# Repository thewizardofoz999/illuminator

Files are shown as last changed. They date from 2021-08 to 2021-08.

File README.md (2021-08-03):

# Illuminator

Completely open-source LED board for FRC visual processing tasks.

Idea based on: Sneaky Snakes' Gloworm LEDboard: https://github.com/KahramanAkyuz/Gloworm and
               Gloworm Vision's Gloworm: https://github.com/gloworm-vision/gloworm

Index:

• "Illuminator" is the first version of the design.

• "Illuminator BOOST" is an upgrade board for ILL.v1.

• "Illuminator" is the second version. This version has a MCU (ATmega328) and temperature sensors on both side of the board. Thus it can work with a closed feedback loop algorithm. We'we written an Arduino IDE library for the v2 board. Library files are also included in the repository in software folder.

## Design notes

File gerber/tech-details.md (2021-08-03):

# PCB Specifications:

Layers: 2 Layers

Min Track/Spacing: 6/6mil

Min Hole Size: 0.3mm

Via Process: Tenting vşas

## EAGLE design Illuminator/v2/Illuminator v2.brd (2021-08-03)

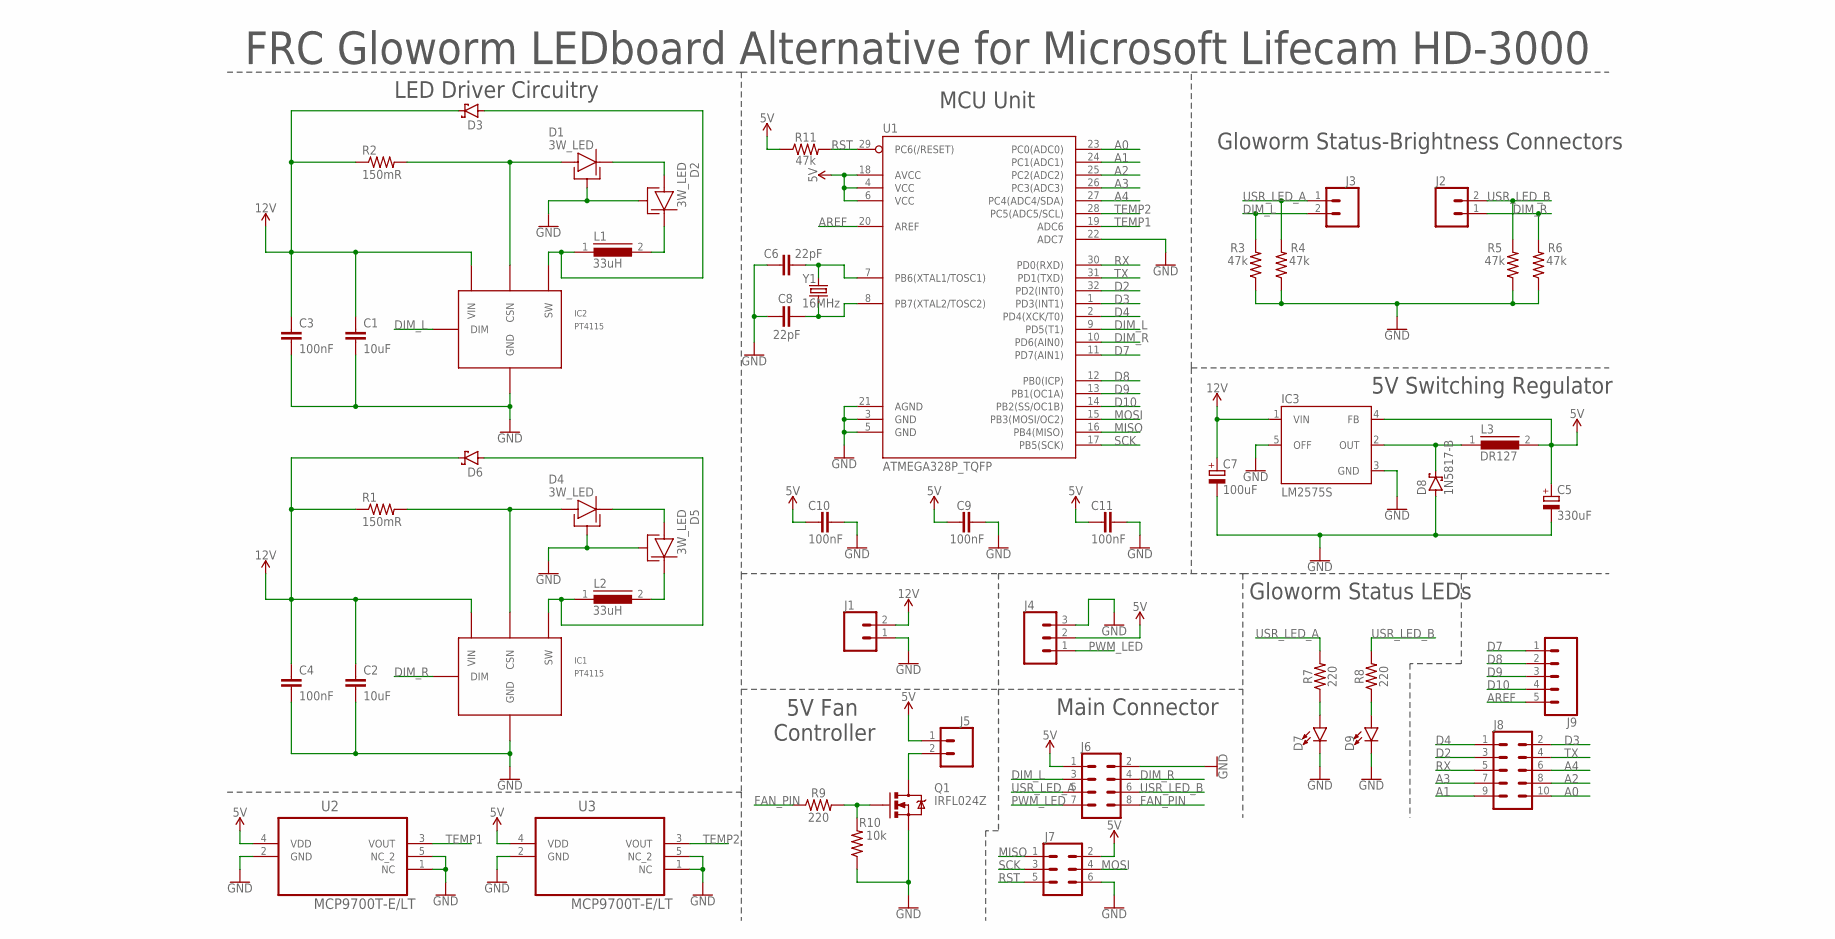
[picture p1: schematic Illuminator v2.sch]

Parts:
C1, C2: 10uF; 1206
C3, C4, C9, C10, C11: 100nF; 0805
C5: 330uF; CAPAE1030X1050N
C6, C8: 22pF; 0603
C7: 100uF; CAPAE830X1050N
D1, D2, D4, D5: 3W_LED
D3, D6: SCHOTTKY-DIODESMD; SMB
D7, D9: LED1206; LED-1206
D8: 1N5817-B; DO41-7.6
IC1, IC2: PT4115
IC3: LM2575S; TO263-5
J1: CONN_02SPRING-2.54-RA; SPRINGTERMINAL-2.54MM-2
J2, J3, J5: CONN_02; 1X02
J4: CONN_03; 1X03
J6: CONN_04X2; 2X4
J7: CONN_03X2NO_SILK; 2X3-NS
J8: CONN_05X2NO_SILK; 2X5_NOSILK
J9: CONN_05NO_SILK; 1X05_NO_SILK
L1, L2: 33uH; DR125
L3: DR127
Q1: IRFL024Z; SOT-223
R1, R2: 150mR; R2512
R3, R4, R5, R6, R11: 47k; 0805
R7, R8, R9: 220; 1206
R10: 10k; 1206
U1: ATMEGA328P_TQFP; TQFP32-08
U2, U3: MCP9700T-E/LT; SOT65P210X110-5N
Y1: 16MHz; CRYSTAL-SMD-5X3.2-4PAD

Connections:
5V: C5.1 (+), C9.1, C10.1, C11.1, IC3.4 (FB), J4.2, J5.1, J6.1, J7.2, L3.2, R11.1, U1.4 (VCC), U1.6 (VCC), U1.18 (AVCC), U2.4 (VDD), U3.4 (VDD)
12V: C1.1, C2.1, C3.1, C4.1, C7.1 (+), D3.C, D6.C, IC1.5 (VIN), IC2.5 (VIN), IC3.1 (VIN), J1.2, R1.1, R2.1
A0: J8.10, U1.23 (PC0(ADC0))
A1: J8.9, U1.24 (PC1(ADC1))
A2: J8.8, U1.25 (PC2(ADC2))
A3: J8.7, U1.26 (PC3(ADC3))
A4: J8.6, U1.27 (PC4(ADC4/SDA))
AREF: J9.5, U1.20 (AREF)
D2: J8.3, U1.32 (PD2(INT0))
D3: J8.2, U1.1 (PD3(INT1))
D4: J8.1, U1.2 (PD4(XCK/T0))
D7: J9.1, U1.11 (PD7(AIN1))
D8: J9.2, U1.12 (PB0(ICP))
D9: J9.3, U1.13 (PB1(OC1A))
D10: J9.4, U1.14 (PB2(SS/OC1B))
DIM_L: IC2.3 (DIM), J3.2, J6.3, R3.2, U1.9 (PD5(T1))
DIM_R: IC1.3 (DIM), J2.1, J6.4, R6.2, U1.10 (PD6(AIN0))
FAN_PIN: J6.8, R9.1
GND: C1.2, C2.2, C3.2, C4.2, C5.2 (-), C6.1, C7.2 (-), C8.1, C9.2, C10.2, C11.2, D1.B_PAD, D2.B_PAD, D4.B_PAD, D5.B_PAD, D7.C, D8.A, D9.C, IC1.2 (GND), IC1.2A (GND), IC2.2 (GND), IC2.2A (GND), IC3.3 (GND), IC3.5 (OFF), J1.1, J4.3, J6.2, J7.6, Q1.3 (S), R3.1, R4.1, R5.1, R6.1, R10.1, U1.3 (GND), U1.5 (GND), U1.21 (AGND), U1.22 (ADC7), U2.1 (NC), U2.2 (GND), U2.5 (NC_2), U3.1 (NC), U3.2 (GND), U3.5 (NC_2)
MISO: J7.1, U1.16 (PB4(MISO))
MOSI: J7.4, U1.15 (PB3(MOSI/OC2))
unnamed: D4.ANODE, IC1.4 (CSN), R1.2
unnamed: D1.ANODE, IC2.4 (CSN), R2.2
unnamed: D1.CATHODE, D2.ANODE
unnamed: D3.A, IC2.1 (SW), L1.1
unnamed: D2.CATHODE, L1.2
unnamed: D4.CATHODE, D5.ANODE
unnamed: D6.A, IC1.1 (SW), L2.1
unnamed: D5.CATHODE, L2.2
unnamed: C8.2, U1.8 (PB7(XTAL2/TOSC2)), Y1.1
unnamed: D8.C, IC3.2 (OUT), L3.1
unnamed: D7.A, R7.1
unnamed: D9.A, R8.1
unnamed: Q1.1 (G), R9.2, R10.2
unnamed: J5.2, Q1.2 (D), Q1.4 (D)
unnamed: C6.2, U1.7 (PB6(XTAL1/TOSC1)), Y1.3 (2)
PWM_LED: J4.1, J6.7
RST: J7.5, R11.2, U1.29 (PC6(/RESET))
RX: J8.5, U1.30 (PD0(RXD))
SCK: J7.3, U1.17 (PB5(SCK))
TEMP1: U1.19 (ADC6), U2.3 (VOUT)
TEMP2: U1.28 (PC5(ADC5/SCL)), U3.3 (VOUT)
TX: J8.4, U1.31 (PD1(TXD))
USR_LED_A: J3.1, J6.5, R4.2, R7.2
USR_LED_B: J2.2, J6.6, R5.2, R8.2

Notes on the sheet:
FRC Gloworm LEDboard Alternative for Microsoft Lifecam HD-3000
LED Driver Circuitry
5V Switching Regulator
5V Fan Controller
Gloworm Status-Brightness Connectors
Gloworm Status LEDs
Main Connector
MCU Unit

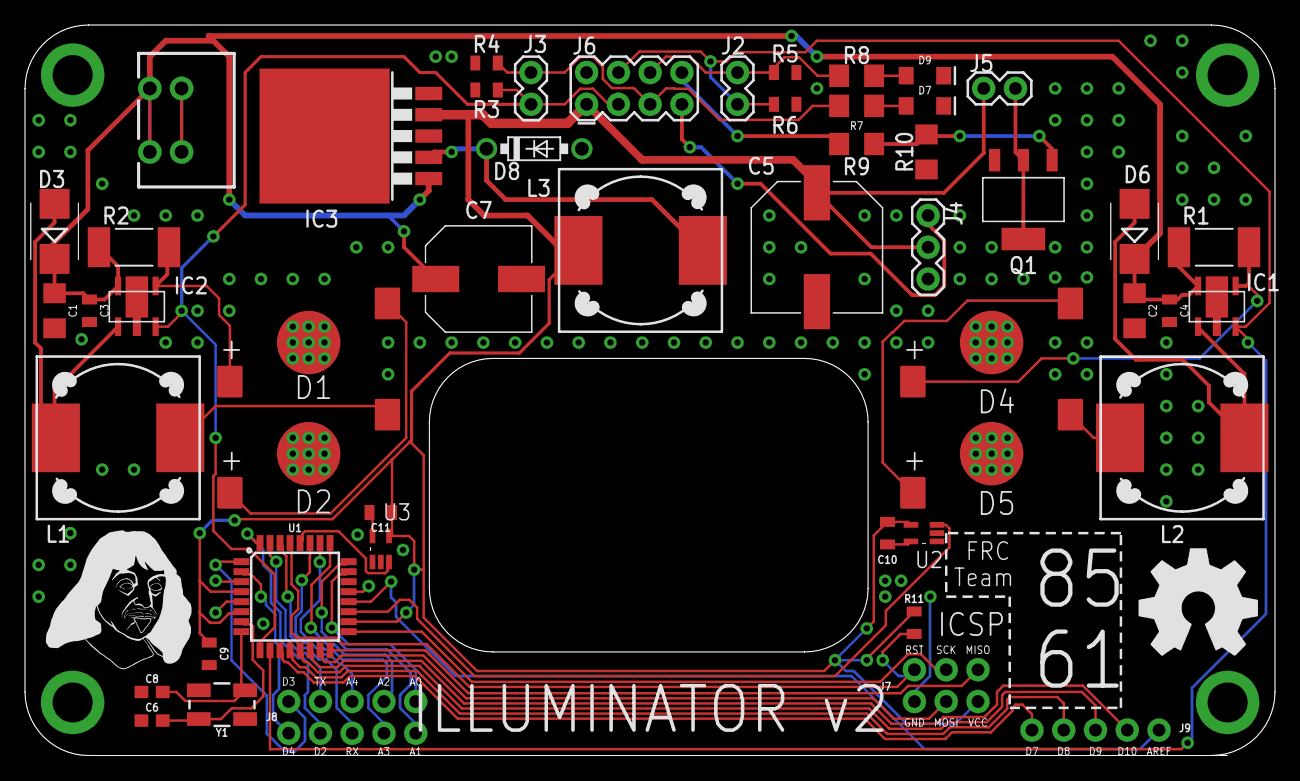
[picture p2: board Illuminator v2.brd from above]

Board: 2 copper layers, 99.9 x 58.4 mm, 51 parts (0 on the bottom side), 45 nets.

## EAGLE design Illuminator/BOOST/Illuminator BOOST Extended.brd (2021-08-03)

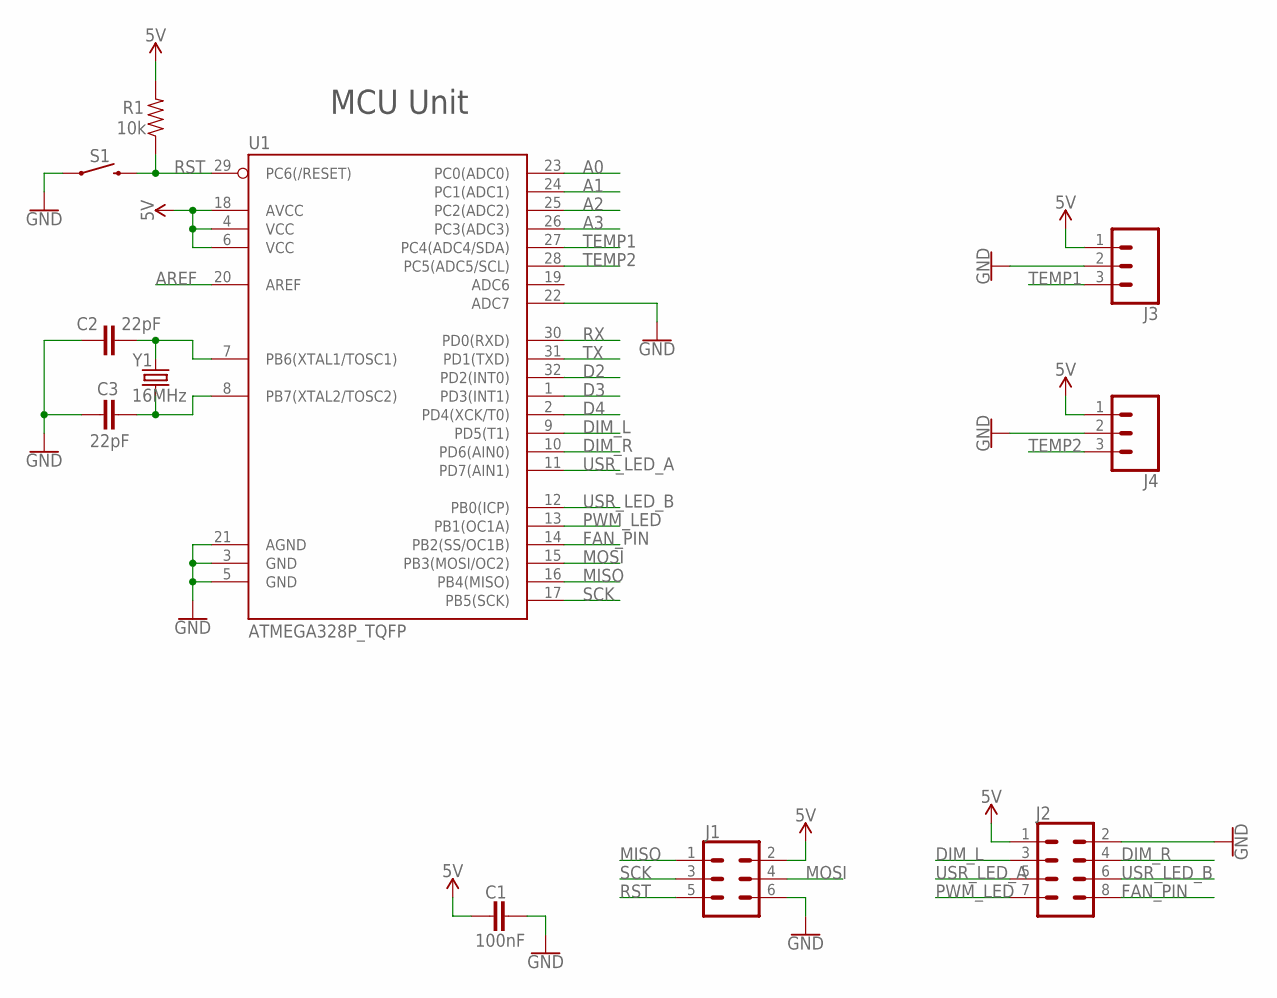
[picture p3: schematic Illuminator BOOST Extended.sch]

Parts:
C1: 100nF; 0805
C2, C3: 22pF; 0603
J1: CONN_03X2NO_SILK; 2X3-NS
J2: CONN_04X2; 2X4
J3, J4: CONN_03JST-PTH-VERT; JST-3-PTH-VERT
R1: 10k; 1206
S1: MOMENTARY-SWITCH-SPST-SMD-6.0X3.5MM; TACTILE_SWITCH_SMD_6.0X3.5MM
U1: ATMEGA328P_TQFP; TQFP32-08
Y1: 16MHz; CRYSTAL-SMD-5X3.2-4PAD

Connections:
5V: C1.1, J1.2, J2.1, J3.1, J4.1, R1.2, U1.4 (VCC), U1.6 (VCC), U1.18 (AVCC)
A0: U1.23 (PC0(ADC0))
A1: U1.24 (PC1(ADC1))
A2: U1.25 (PC2(ADC2))
A3: U1.26 (PC3(ADC3))
AREF: U1.20 (AREF)
D2: U1.32 (PD2(INT0))
D3: U1.1 (PD3(INT1))
D4: U1.2 (PD4(XCK/T0))
DIM_L: J2.3, U1.9 (PD5(T1))
DIM_R: J2.4, U1.10 (PD6(AIN0))
FAN_PIN: J2.8, U1.14 (PB2(SS/OC1B))
GND: C1.2, C2.1, C3.1, J1.6, J2.2, J3.2, J4.2, S1.1, U1.3 (GND), U1.5 (GND), U1.21 (AGND), U1.22 (ADC7)
MISO: J1.1, U1.16 (PB4(MISO))
MOSI: J1.4, U1.15 (PB3(MOSI/OC2))
unnamed: C3.2, U1.8 (PB7(XTAL2/TOSC2)), Y1.1
unnamed: C2.2, U1.7 (PB6(XTAL1/TOSC1)), Y1.3 (2)
PWM_LED: J2.7, U1.13 (PB1(OC1A))
RST: J1.5, R1.1, S1.2, U1.29 (PC6(/RESET))
RX: U1.30 (PD0(RXD))
SCK: J1.3, U1.17 (PB5(SCK))
TEMP1: J3.3, U1.27 (PC4(ADC4/SDA))
TEMP2: J4.3, U1.28 (PC5(ADC5/SCL))
TX: U1.31 (PD1(TXD))
USR_LED_A: J2.5, U1.11 (PD7(AIN1))
USR_LED_B: J2.6, U1.12 (PB0(ICP))

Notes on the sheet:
MCU Unit

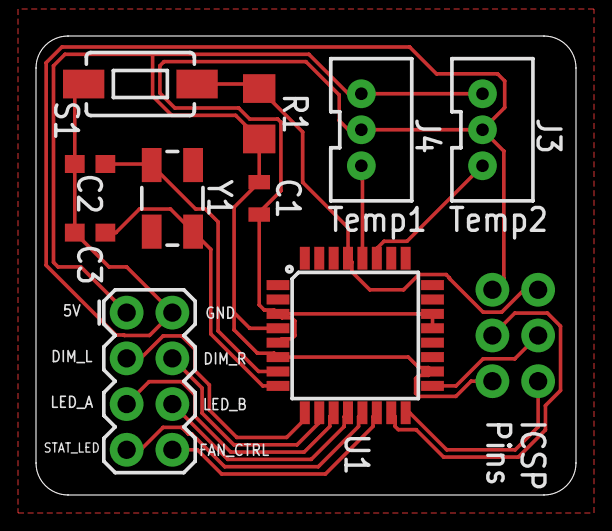
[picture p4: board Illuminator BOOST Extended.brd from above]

Board: 2 copper layers, 30.0 x 25.5 mm, 11 parts (0 on the bottom side), 16 nets.

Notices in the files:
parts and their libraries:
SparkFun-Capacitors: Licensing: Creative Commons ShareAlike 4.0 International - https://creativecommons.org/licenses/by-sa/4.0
